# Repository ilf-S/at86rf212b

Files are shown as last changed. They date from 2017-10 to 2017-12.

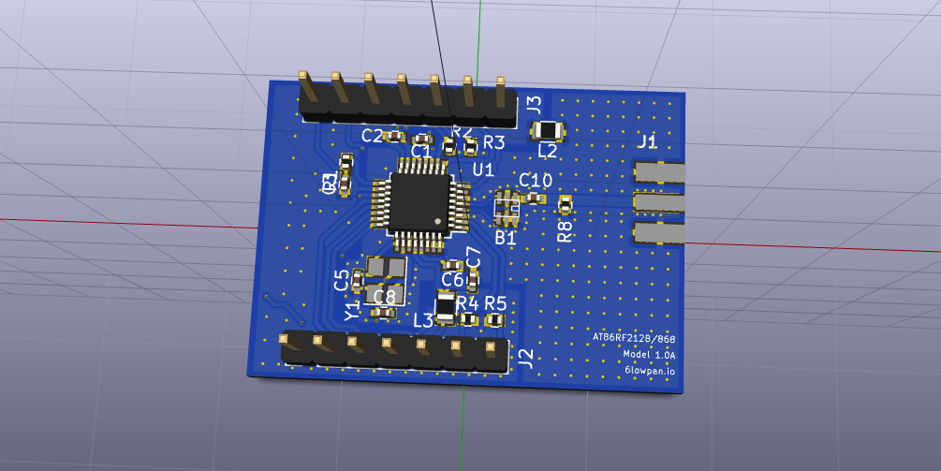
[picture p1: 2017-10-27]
at86rf212b_2l.png

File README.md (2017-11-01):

##
Kicad project files for a 2 layer PCB with AT86RF212B transceiver. The board uses separated digital and analog ground planes on a 2 layer PCB design. Board has not been tested yet, so use with caution.

##
1. 2 Layer design
2. 4 Ground planes: Digital, Analog, Xtal & RF
	* Digital handles all signals like SPI connection, IRQ, etc.
	* Analog is mostly for things connected to the RF/Xtal, etc. but is confined bellow the IC QFN package. Consult the documentation, all analog ground pins are connected to the pads bellow the QFN.
	* The RF is a separate plane connected to the IC by the two analog GND pins surrounding the RF_P/RF_N pins. Again consult the documentation
	* The Xtal GND plane is connected to the IC with a single Analog GND pin and is hard grounded with via stitches. This hopefully will help with interference with the nearby IRQ pin. Capacitance could be an issue, though, might need some tweaking.

##
The rest is straight forward. Just follow the AT86RF212B Atmel SpecSheet.

##
**Still not tested!**

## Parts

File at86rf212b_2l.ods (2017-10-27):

Reference | Value | Footprint | Count | Datasheet | FootprintLib
U1 | AT86RF212B | LQFP-32-1EP_5x5mm_Pitch0.5mm | 1 |  | Housings_QFP | v
L2 | FB2 | R_0805 | 1 |  | Resistors_SMD | v
L3 | FB1 | R_0805 | 1 |  | Resistors_SMD | v
Y1 | 16.0Mhz | Crystal_SMD_3225-4pin_3.2x2.5mm | 1 |  | Crystals | v
C5 C8 | 10pF | C_0402 | 2 |  | Capacitors_SMD | v
C6 C7 C1 C2 | 1uF | C_0402 | 4 |  | Capacitors_SMD | v
R1 | 470 | R_0402 | 1 |  | Resistors_SMD | v
C3 | 2.2pF | C_0402 | 1 |  | Capacitors_SMD | v
B1 | BALUN | BALUN | 1 |  | makerlab | v
J1 | Conn_Coaxial | SMA_EDGELAUNCH | 1 |  | adafruit | v
C10 | 100pF | C_0402 | 1 |  | Capacitors_SMD | v
R3 R2 R4 R5 | 0 | R_0402 | 4 |  | Resistors_SMD | v
J2 J3 | Conn_01x07 | Pin_Header_Straight_1x07_Pitch2.54mm | 2 |  | Pin_Headers | v
R8 | 10k | R_0402 | 1 |  | Resistors_SMD | v/v
R6 | 22 | R_0402 | 1 |  | Resistors_SMD | v

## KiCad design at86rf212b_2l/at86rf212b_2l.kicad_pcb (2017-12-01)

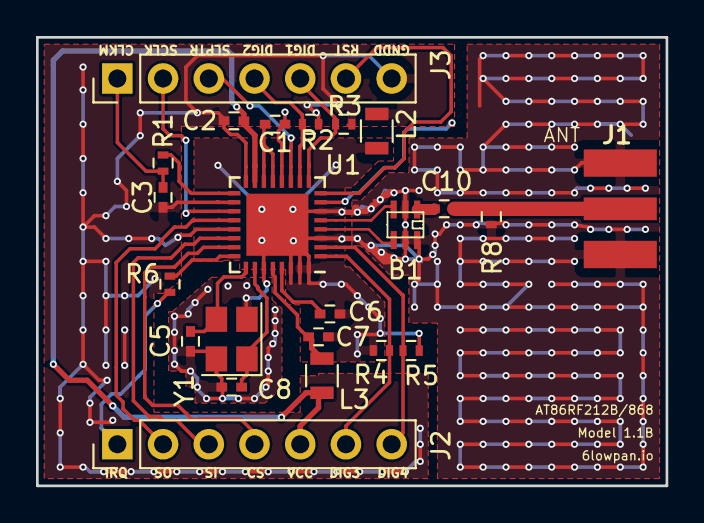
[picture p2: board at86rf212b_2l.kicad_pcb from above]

Board: 2 copper layers, 35.0 x 24.9 mm, 23 parts (0 on the bottom side), 26 nets.

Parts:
B1: BALUN
C1, C2, C6, C7: 1uF; C_0402
C3: 2.2pF; C_0402
C5, C8: 10pF; C_0402
C10: 100pF; C_0402
J1: ANT; SMA_EDGELAUNCH
J2, J3: Conn_01x07; Pin_Header_Straight_1x07_Pitch2.54mm
L2: FB2; R_0805
L3: FB1; R_0805
R1: 470; R_0402
R2, R3, R4, R5: 0; R_0402
R6: 22; R_0402
R8: 10k; R_0402
U1: AT86RF212B; QFN-32-1EP_5x5mm_Pitch0.5mm
Y1: 16.0Mhz; Crystal_SMD_3225-4pin_3.2x2.5mm

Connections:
/CLKM: C3.1, J3.1, R1.1
/CS: J2.4, U1.23
/DIG1: J3.5, R3.2, U1.9
/DIG2: J3.4, R2.2, U1.10
/DIG3: J2.6, R4.2, U1.1
/DIG4: J2.7, R5.2, U1.2
/IRQ: J2.1, R6.2
/MISO: J2.2, U1.20
/MOSI: J2.3, U1.22
/RST: J3.6, U1.8
/SCLK: J3.2, U1.19
/SLPTR: J3.3, U1.11
GND: B1.2, B1.5, B1.6, C5.1, C6.1, C7.1, C8.1, J1.GND, L2.1, R4.1, R5.1, R8.1, U1.3, U1.6, U1.27, U1.30, U1.31, U1.32, U1.33, Y1.2, Y1.4
GNDPWR: C1.2, C2.2, C3.2, J3.7, L2.2, R2.1, R3.1, U1.7, U1.12, U1.16, U1.18, U1.21
unnamed: B1.1, C10.2
unnamed: B1.3, U1.5
unnamed: B1.4, U1.4
unnamed: C1.1, U1.13, U1.14
unnamed: C5.2, U1.25, Y1.3
unnamed: C6.2, U1.29
unnamed: C8.2, U1.26, Y1.1
unnamed: C10.1, J1.P, R8.2
unnamed: R1.2, U1.17
unnamed: R6.1, U1.24
VCC: C2.1, J2.5, L3.2, U1.15
VDD: C7.2, L3.1, U1.28

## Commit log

2017-10-27 Initial import of Kicad project files for AT86RF212B transceiver
    [at86rf212b_2l.csv, at86rf212b_2l.kicad_pcb, at86rf212b_2l.ods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]
2017-10-28 Moving the kicad project files in a separate directory. Adding directory with gerber plots
    [at86rf212b_2l.kicad_pcb, at86rf212b_2l.sch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]
2017-10-28 clean up the root directory
    [at86rf212b_2l.kicad_pcb, at86rf212b_2l.sch]
2017-10-28 further clean-up
    [at86rf212b_2l.csv]
2017-10-28 clean up
    [at86rf212b_2l-B.Adhes.gbr, at86rf212b_2l-B.Cu.gbr, at86rf212b_2l-B.Mask.gbr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]
2017-10-28 Fix the Analog and Digital Ground connections for pins DIG1,DIG2,DIG3,DIG4. Were swapped in the previous version
    [at86rf212b_2l-B.Adhes.gbr, at86rf212b_2l-B.Cu.gbr, at86rf212b_2l-B.Mask.gbr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]
2017-10-28 latest fixes on vias, layers, pads for the SMA antenna and the edge cuts area.
    [at86rf212b_2l-B.Adhes.gbr, at86rf212b_2l-B.Cu.gbr, at86rf212b_2l-B.Mask.gbr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]
2017-10-28 minor move of some vias around the antenna feed line
    [at86rf212b_2l-B.Adhes.gbr, at86rf212b_2l-B.Cu.gbr, at86rf212b_2l-B.Mask.gbr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]
2017-11-01 Latest commits. Splitting ground planes in 4: Digital, Analog, Xtal & RF. All 4 connected in the QFN package, essentially following a "star" formation. Spacing is around 12 mils, so most fabs can han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
    Also latest Gerber plots in the plots directory.
    [at86rf212b_2l-B.Adhes.gbr, at86rf212b_2l-B.Cu.gbr, at86rf212b_2l-B.Mask.gbr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]
2017-11-01 More explanation around the design and the current state.
2017-12-01 AT86RFR212b package, mistakenly used QFP instaed of the proper QFN 32 bit package. Now fixed. That lead to some minor tweaks and fixes around the ground planes. Also moved the resistor for the IRQ, e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
    [at86rf212b_2l-B.Adhes.gbr, at86rf212b_2l-B.Cu.gbr, at86rf212b_2l-B.Mask.gbr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]
